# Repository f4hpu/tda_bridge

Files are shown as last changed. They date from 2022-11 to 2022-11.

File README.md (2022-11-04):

<h1 align="center">The tda_bridge Project</h1>




[FR en Français](./documentation/README_fr.md)

This repository contains a [KiCAD 6.0.9](https://www.kicad.org/) project for an electronics board (hardware).

This electronics board is a bridgeable audio stereo amplifier, based on a pair of TDA7293 chips.

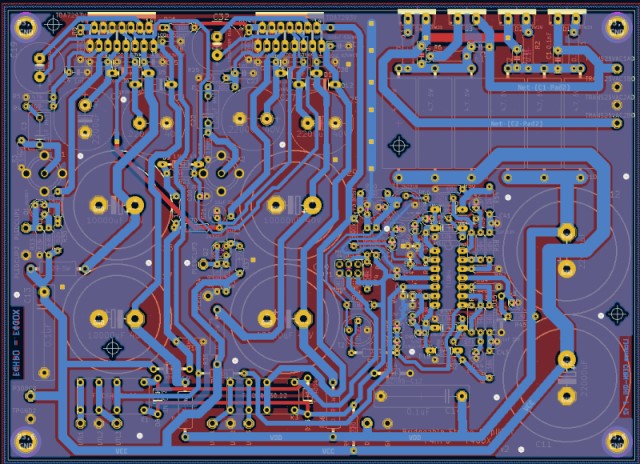
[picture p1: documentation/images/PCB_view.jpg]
PCB image


## Concept

The schematics around the TDA7293 was inspired by ST [datasheet](http://www.st.com/web/en/resource/technical/document/datasheet/CD00001887.pdf) and improved by [Francis Ibre for better sound.](http://www.cinetson.org/phpBB3/electronique-f13/1er-ampli-diy-question-diverse-t17238-30.html)

It includes onboard the same card both a power Supply and a watchdog to protect the loudspeakers against continuous voltage.

In addition, this stereo amplifier could easily be converted into a high power mono amplifier (bridge mode) by soldering R26, removing R28 and shunting R25.

## Historical background

A first implementation was made by authors (F4HPU and F4GUX) as reported in [Fangorn's blog](http://fangorn.over-blog.org/article-23233481.html).

Then, a first design was started using [Eagle (free version)](https://www.autodesk.fr/products/eagle/free-download) in 2014. The design then stoped as the size of the board was beyond the limitation of the free version of the CAD software.

Fortunately, in the mean time KiCAD team upgraded highly this wonderful tool and the project could be switched seamlessly to KiCAD 6.0.9.

For this historical reason, the 3D view of the card is not working well as there was no 3D view for the libraries converted from Eagle.

## Technical information

| Characteristics | Value |
| --- | --- |
| Output Power in 8 ohm | 2x70W (stereo) or 1x280W (bridged) |
| Circuit Dimensions | 176.5mm x 128.5 mm |

## Building a tda_bridge card

You have two options wether you wish to build the project as is (i.e. without using KiCAD), or tweak it to fit to your needs:

1. Download the [latest release](https://github.com/f4hpu/tda_bridge/releases/download/v0.0.0-alpha/fabrication.tar.gz) of this project "as is". This archive encloses a BOM (list of components), a directory with the gerber files, and useful pdf files.
2. or git clone this repo (or even download a zip of the directory) and install [KiCAD 6.0.9](https://www.kicad.org/) to open the project. From here, you can tweak the schematics, the routing and generate your Gerber files.

Once you have the gerber files, you can build the 2-sided PCB.

In case you wish to use a single sided PCB, authors guess that's possible if you put straps for the few missing connections. The ground plane effect may be less effective and the noise floor may rise up a little.

KiCAD offers the possibility to print a BOM to buy everything you need for the card by itself. But of course you may want to add some other stuffs, like the power supply transformer, a power switch, a potentiometer to control the output level, a box, a big heatsink (around ~0.4deg/W) for both the TDA7293's and the Diode's. You may find some inspiration in 
[Fangorn's blog - article 1](http://fangorn.over-blog.org/article-22214740.html)/[article 2](http://fangorn.over-blog.org/article-23233481.html), or [Erriez Guitar Amplifier](https://github.com/Erriez/DualTDA7293PowerAmplifier)

### Continuous voltage protection

A continuous voltage may arm the speaker. For this reason, authors included a circuit continuously watching both left and right outputs. In case of any failure both left and right speakers are disconnected.

The system is a custom design by F4HPU and F4GUX, which behavior was simulated using [LTSpice](https://www.analog.com/en/design-center/design-tools-and-calculators/ltspice-simulator.html).

A Jumper was included to select between using this watchdog, or bypassing it.

### Bridge mode

The Bridge mode is a special mode where the two lines of the stereo amplifier are used simultaneously to drive a single loudspeaker. Simply speaking, for an input signal V_in, left output is (A.V_in), while right output is (-A.V_in), therefore output between left and right is four times higher (as voltage is twice higher).

If you foresee to use this amplifier as a _stereo amplifier_ you need to: remove R26, solder R28, solder R25. In this case, the speakers shall be connected between ground and output_left for left speaker, and ground and output_right for right speaker.

But if you foresee to use this amplifier as a _high power mono amplifier_ you need to: solder R26, remove R28, replace R25 by a shunt. In this case, the speaker shall be connected between output_left and output_right.

## Licencing and Property

The design was made by F4HPU and F4GUX, who are [French Amateur Radio Operators.](https://www.r-e-f.org/)

Both Schematics and PCB are licensed under [CERN-OHL-P version 2](https://cern-ohl.web.cern.ch/home). 

IMPORTANT NOTE: CURRENT DESIGN HAS NEVER BEEN TESTED FOR REAL YET, SO BE CAREFULL, USE AT YOUR OWN RISKS.

For this reason, you are highly encouraged to check each functionnality step by step.

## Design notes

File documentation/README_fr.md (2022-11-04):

<h1 align="center">Projet tda_bridge</h1>




[ENUS in English](../README.md)

Ce dépôt contient un projet [KiCAD 6.0.9](https://www.kicad.org/) pour une carte électronique (hardware).

Cette carte électronique est un amplificateur stéréo audio avec option mode ponté (bridged), basé sur une paire de circuits TDA7293.

PCB image

## Concept

Le schéma autour du TDA7293 s'inspire de la [documentation ST](http://www.st.com/web/en/resource/technical/document/datasheet/CD00001887.pdf) et amélioré par [Francis Ibre pour un meilleur son.](http://www.cinetson.org/phpBB3/electronique-f13/1er-ampli-diy-question-diverse-t17238-30.html)

Il inclut sur la même carte à la fois une alimentation et un chien de garde pour protéger les haut-parleurs contre les tensions continues.

En outre, cet amplificateur stéréo pourrait facilement être converti en un amplificateur mono de haute puissance (mode pont) en soudant R26, en enlevant R28 et en shuntant R25.

## Bref historique

Une première implémentation a été réalisée par les auteurs (F4HPU et F4GUX) comme indiqué dans [le blog de Fangorn](http://fangorn.over-blog.org/article-23233481.html).

Ensuite, un premier design a été commencé en utilisant [Eagle (version libre)](https://www.autodesk.fr/products/eagle/free-download) en 2014. Le design s'est ensuite arrêté car la taille de la carte dépassait les limitations de la version gratuite du logiciel de CAO.

Heureusement, entre-temps, l'équipe de KiCAD a mis à niveau ce merveilleux outil et le projet a pu passer sans problème à KiCAD 6.0.9.

Pour cette raison historique, la vue 3D de la carte ne fonctionne pas bien car il n'y avait pas de vue 3D pour les bibliothèques converties depuis Eagle.

## Données Techniques

| Characteristiques | Valeurs |
| --- | --- |
| Puissance de Sortie dans 8 ohms | 2x70W (stereo) or 1x280W (ponté) |
| Dimensions du Circuit | 176.5mm x 128.5 mm |

## Construction d'une carte tda_bridge

Vous avez deux options : soit vous souhaitez construire le projet tel quel (c'est-à-dire sans utiliser KiCAD), soit vous souhaitez le modifier pour l'adapter à vos besoins :

1. Téléchargez la [dernière release] (https://github.com/f4hpu/tda_bridge/releases/download/v0.0.0-alpha/fabrication.tar.gz) de ce projet "tel quel". L'archive contient la BOM (liste de composants), un répertoire avec les fichiers gerber, et des fichiers pdf utiles.
2. ou clonez ce dépôt git (ou même téléchargez un zip du répertoire) et installez [KiCAD 6.0.9](https://www.kicad.org/) pour ouvrir le projet. A partir de là, vous pouvez modifier les schémas, le routage et générer vos fichiers Gerber.

Une fois que vous avez des fichiers gerber, vous pouvez construire le PCB double-face.

Si vous souhaitez utiliser un PCB simple face, les auteurs pensent que c'est possible si vous mettez des straps pour les quelques connexions manquantes. L'effet du plan de masse peut être moins efficace et le bruit de fond peut augmenter un peu.

KiCAD offre la possibilité d'imprimer une nomenclature pour acheter tout ce dont vous avez besoin pour la carte en elle-même. Mais bien sûr, vous pouvez vouloir ajouter d'autres choses, comme le transformateur d'alimentation, un interrupteur, un potentiomètre pour contrôler le niveau de sortie, un boîtier, un grand dissipateur thermique (environ ~0.4deg/W) à la fois pour les TDA7293 et les diodes. Vous pouvez trouver de l'inspiration dans
[blog de Fangorn - article 1](http://fangorn.over-blog.org/article-22214740.html)/[article 2](http://fangorn.over-blog.org/article-23233481.html), ou [l'ampli de guitare de Erriez](https://github.com/Erriez/DualTDA7293PowerAmplifier)

### Protection contre les tensions continues

Une tension continue peut abîmer un haut-parleur. Pour cette raison, les auteurs ont inclus un circuit qui surveille en permanence les deux sorties gauche et droite. En cas de défaillance, les haut-parleurs gauche et droit sont déconnectés.

Le système est une conception personnalisée par F4HPU et F4GUX, dont le comportement a été simulé en utilisant [LTSpice](https://www.analog.com/en/design-center/design-tools-and-calculators/ltspice-simulator.html).

Un cavalier a été inclus pour choisir d'utiliser ce chien de garde ou de le contourner.

### Mode ponté (Bridged)

Le mode ponté (bridged) est un mode spécial où les deux lignes de l'amplificateur stéréo sont utilisées simultanément pour piloter un seul haut-parleur. En clair, pour un signal d'entrée V_in, la sortie gauche est (A.V_in), tandis que la sortie droite est (-A.V_in). Ce faisant, la puissance de sortie se trouve quatre fois plus élevée (car la tension est deux fois plus élevée).

Si vous prévoyez d'utiliser cet amplificateur comme un _amplificateur stéréo_, vous devez : enlever R26, souder R28, souder R25. Dans ce cas, les enceintes doivent être connectées entre la masse et la sortie_gauche pour l'enceinte gauche, et la masse et la sortie_droite pour l'enceinte droite.

Mais si vous prévoyez d'utiliser cet amplificateur comme un _amplificateur mono de forte puissance_ vous devez : souder R26, enlever R28, remplacer R25 par un shunt (court-circuit). Dans ce cas, le haut-parleur doit être connecté entre output_left et output_right.

## Licences et propriété

La conception a été réalisée par F4HPU et F4GUX, qui sont [des radioamateurs français] (https://www.r-e-f.org/).

Les schémas et le PCB sont sous licence "Open Hardware" [CERN-OHL-P version 2](https://cern-ohl.web.cern.ch/home).

NOTE IMPORTANTE : LA CONCEPTION ACTUELLE N'A ENCORE JAMAIS ÉTÉ VRAIMENT TESTÉE, DONC SOYEZ PRUDENT, UTILISEZ À VOS PROPRES RISQUES.

Pour cette raison, vous êtes fortement encouragés à vérifier chaque fonctionnalité étape par étape.

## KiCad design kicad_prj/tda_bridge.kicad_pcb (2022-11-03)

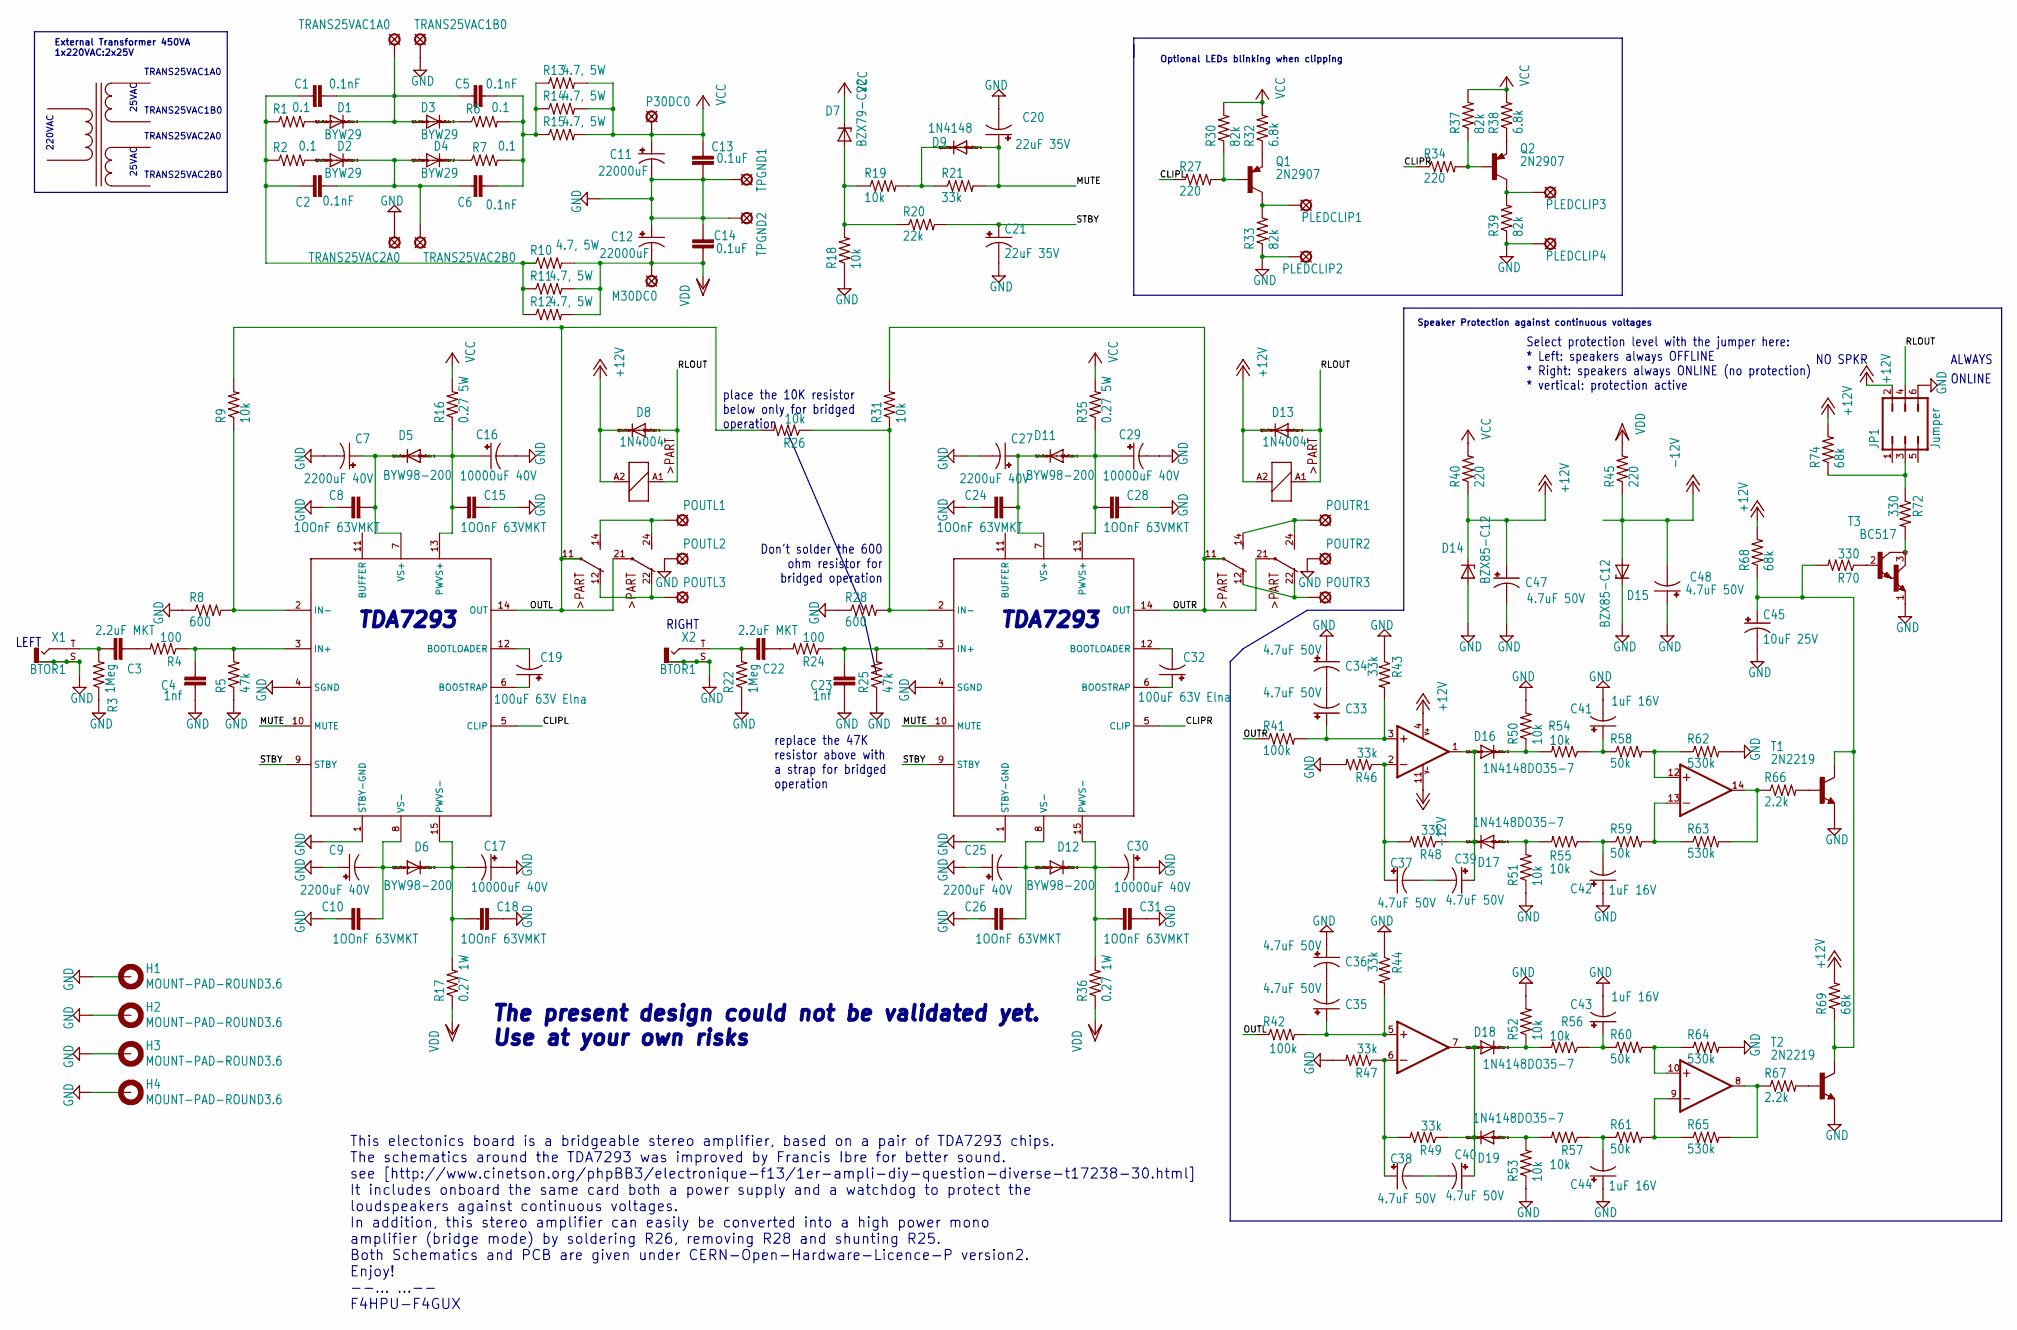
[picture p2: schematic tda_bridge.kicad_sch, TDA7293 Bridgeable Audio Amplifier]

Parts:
C1, C2, C5, C6: 0.1nF; C5B2.5
C3, C22: C075-063X106
C4, C23: C050-030X075
C7, C9, C25, C27: 2200uF 40V; E7,5-18
C8, C10, C15, C18, C24, C26, C28, C31: 1OOnF 63VMKT; C050-025X075
C11, C12: 22000uF; EB35D
C13, C14: 0.1uF; C22.5B6
C16, C17, C29, C30: 10000uF 40V; EB30D
C19, C32: 100uF 63V Elna; E5-13
C20, C21: 22uF 35V; E2-5
C33, C34, C35, C36, C37, C38, C39, C40, C47, C48: 4.7uF 50V; E1,8-4
C41, C42, C43, C44: 1uF 16V; E1,8-4
C45: 10uF 25V; E1,8-4
D1, D2, D3, D4: BYW29; DO220S
D5, D6, D11, D12: BYW98-200; F126-10
D7, D14, D15: DO41Z10
D8, D13: 1N4004; DO41-10
D9: 1N4148; DO35-10
D16, D17, D18, D19: 1N4148DO35-7; DO35-7
H1, H2, H3, H4: MOUNT-PAD-ROUND3.6; 3,6-PAD
IC1, IC2: TDA7293V; MULTIWATT15V
IC3: TL084; DIL14
JP1: Jumper; JP3Q
K1, K3: FINDER-30.22
M30DC0: SE13
P30DC0: SE13
PLEDCLIP1, PLEDCLIP2, PLEDCLIP3, PLEDCLIP4: SE13
POUTL1, POUTL2, POUTL3: SE13
POUTR1, POUTR2, POUTR3: SE13
Q1, Q2: 2N2907; TO18
R1, R2, R6, R7: 0.1; 0309_10
R3, R22: 1Meg; 0207_7
R4, R24: 100; 0207_7
R5, R25: 47k; 0207_7
R8, R28: 600; 0207_7
R9, R31: 10k; 0617_22
R10, R11, R12, R13, R14, R15: 4.7, 5W; VTA52
R16, R35: 0.27 5W; 0411_15
R17, R36: 0.27 1W; 0411_15
R18, R19, R26, R50, R51, R52, R53, R54, R55, R56, R57: 10k; 0207_7
R20: 22k; 0207_12
R21, R48, R49: 33k; 0207_7
R27, R34, R45: 220; 0207_7
R30, R33, R37, R39: 82k; 0207_7
R32, R38: 6.8k; 0207_7
R40: 220; 0207_12
R41: 100k; 0207_7
R42: 100k; 0207_12
R43, R44, R46, R47: 33k; 0207_2V
R58, R59, R60, R61: 50k; 0207_7
R62, R63, R64, R65: 530k; 0207_7
R66: 2.2k; 0207_7
R67: 2.2k; 0207_12
R68, R69, R74: 68k; 0207_7
R70, R72: 330; 0207_7
T1, T2: 2N2219; TO5
T3: BC517; TO92
T4: Transformer_1P_2S
TPGND1, TPGND2: SE13
TRANS25VAC1A0, TRANS25VAC1B0, TRANS25VAC2A0, TRANS25VAC2B0: SE13
X1, X2: BTOR1

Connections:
+12V: C47.+, D8.C, D13.C, D14.C, IC3.4 (V+), JP1.2, K1.A2 (2), K3.A2 (2), R40.1, R68.2, R69.2, R74.2
-12V: C48.-, D15.A, IC3.11 (V-), R45.1
/CLIPL: IC1.5 (CLIP), R27.1
/CLIPR: IC2.5 (CLIP), R34.1
/MUTE: C20.+, D9.A, IC1.10 (MUTE), IC2.10 (MUTE), R21.2
/OUTL: IC1.14 (OUT), K1.11, K1.21, R9.2, R26.2, R42.1
/OUTR: IC2.14 (OUT), K3.11, K3.21, R31.2, R41.1
/RLOUT: D8.A, D13.A, JP1.4, K1.A1 (1), K3.A1 (1)
/STBY: C21.+, IC1.9 (STBY), IC2.9 (STBY), R20.2
GND: C4.2, C7.-, C8.1, C9.+, C10.1, C11.-, C12.+, C13.2, C14.2, C15.1, C16.-, C17.+, C18.1, C20.-, C21.-, C23.2, C24.1, C25.+, C26.1, C27.-, C28.1, C29.-, C30.+, C31.1, C34.+, C36.+, C41.-, C42.+, C43.-, C44.+, C45.-, C47.-, C48.+, D14.A, D15.C, H1.B3,6 (MOUNT), H2.B3,6 (MOUNT), H3.B3,6 (MOUNT), H4.B3,6 (MOUNT), IC1.1 (STBY-GND), IC1.4 (SGND), IC2.1 (STBY-GND), IC2.4 (SGND), JP1.6, PLEDCLIP2.MP, PLEDCLIP4.MP, POUTL2.MP, POUTR2.MP, R3.1, R5.1, R8.1, R18.1, R22.1, R25.1, R28.1, R33.1, R39.1, R43.1, R44.1, R46.2, R47.2, R50.2, R51.1, R52.2, R53.1, R62.2, R64.2, T1.1 (E), T2.1 (E), T3.1 (E), TPGND1.MP, TPGND2.MP, TRANS25VAC1B0.MP, TRANS25VAC2A0.MP, X1.S (2), X1.S@1 (2@1), X1.S@2 (2@2), X1.S@3 (2@3), X2.S (2), X2.S@1 (2@1), X2.S@2 (2@2), X2.S@3 (2@3)
unnamed: C1.1, C2.1, R1.1, R2.1, R10.1, R11.1, R12.1
unnamed: C1.2, C5.1, D1.C, D3.A, TRANS25VAC1A0.MP
unnamed: C2.2, C6.1, D2.C, D4.A, TRANS25VAC2B0.MP
unnamed: C3.1, R3.2, X1.T (1)
unnamed: C3.2, R4.2
unnamed: C4.1, IC1.3 (IN+), R4.1, R5.2
unnamed: C5.2, C6.2, R6.2, R7.2, R13.1, R14.1, R15.1
unnamed: C7.+, C8.2, D5.C, IC1.7 (VS+)
unnamed: C9.-, C10.2, D6.A, IC1.8 (VS-)
unnamed: C15.2, C16.+, D5.A, IC1.13 (PWVS+), R16.1
unnamed: C17.-, C18.2, D6.C, IC1.15 (PWVS-), R17.2
unnamed: C19.+, IC1.6 (BOOSTRAP)
unnamed: C19.-, IC1.12 (BOOTLOADER)
unnamed: C22.1, R22.2, X2.T (1)
unnamed: C22.2, R24.2
unnamed: C23.1, IC2.3 (IN+), R24.1, R25.2
unnamed: C24.2, C27.+, D11.C, IC2.7 (VS+)
unnamed: C25.-, C26.2, D12.A, IC2.8 (VS-)
unnamed: C28.2, C29.+, D11.A, IC2.13 (PWVS+), R35.1
unnamed: C30.-, C31.2, D12.C, IC2.15 (PWVS-), R36.2
unnamed: C32.+, IC2.6 (BOOSTRAP)
unnamed: C32.-, IC2.12 (BOOTLOADER)
unnamed: C33.+, IC3.3 (+IN), R41.2, R43.2
unnamed: C33.-, C34.-
unnamed: C35.+, IC3.5 (+IN), R42.2, R44.2
unnamed: C35.-, C36.-
unnamed: C37.+, IC3.2 (-IN), R46.1, R48.2
unnamed: C37.-, C39.-
unnamed: C38.+, IC3.6 (-IN), R47.1, R49.2
unnamed: C38.-, C40.-
unnamed: C39.+, D16.A, D17.C, IC3.1 (OUT), R48.1
unnamed: C40.+, D18.A, D19.C, IC3.7 (OUT), R49.1
unnamed: C41.+, R54.1, R58.1
unnamed: C42.-, R55.1, R59.1
unnamed: C43.+, R56.1, R60.1
unnamed: C44.-, R57.1, R61.1
unnamed: D1.A, R1.2
unnamed: D2.A, R2.2
unnamed: D3.C, R6.1
unnamed: D4.C, R7.1
unnamed: D7.A, R18.2, R19.1, R20.1
unnamed: D9.C, R19.2, R21.1
unnamed: D16.C, R50.1, R54.2
unnamed: D17.A, R51.2, R55.2
unnamed: D18.C, R52.1, R56.2
unnamed: D19.A, R53.2, R57.2
unnamed: IC1.2 (IN-), R8.2, R9.1
unnamed: IC2.2 (IN-), R26.1, R28.2, R31.1
unnamed: IC3.8 (OUT), R65.2, R67.1
unnamed: IC3.9 (-IN), R61.2, R65.1
unnamed: IC3.10 (+IN), R60.2, R64.1
unnamed: IC3.12 (+IN), R58.2, R62.1
unnamed: IC3.13 (-IN), R59.2, R63.1
unnamed: IC3.14 (OUT), R63.2, R66.1
unnamed: JP1.3, R72.1, R74.1
unnamed: K1.12 (O), K1.22 (O), POUTL3.MP
unnamed: K1.14 (S), K1.24 (S), POUTL1.MP
unnamed: K3.12 (O), K3.22 (O), POUTR3.MP
unnamed: K3.14 (S), K3.24 (S), POUTR1.MP
unnamed: PLEDCLIP1.MP, Q1.3 (C), R33.2
unnamed: PLEDCLIP3.MP, Q2.3 (C), R39.2
unnamed: Q1.1 (E), R32.1
unnamed: Q1.2 (B), R27.2, R30.1
unnamed: Q2.1 (E), R38.1
unnamed: Q2.2 (B), R34.2, R37.1
unnamed: R66.2, T1.2 (B)
unnamed: R67.2, T2.2 (B)
unnamed: C45.+, R68.1, R69.1, R70.2, T1.3 (C), T2.3 (C)
unnamed: R70.1, T3.2 (B)
unnamed: R72.2, T3.3 (C)
VCC: C11.+, C13.1, D7.C, P30DC0.MP, R13.2, R14.2, R15.2, R16.2, R30.2, R32.2, R35.2, R37.2, R38.2, R40.2
VDD: C12.-, C14.1, M30DC0.MP, R10.2, R11.2, R12.2, R17.1, R36.1, R45.2

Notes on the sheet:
25VAC
TRANS25VAC1A0
ALWAYS
Optional LEDs blinking when clipping
TDA7293
ONLINE
NO SPKR
This electonics board is a bridgeable stereo amplifier, based on a pair of TDA7293 chips. The schematics around the TDA7293 was improved by Francis Ibre for better sound. see [http://www.cinetson.org/phpBB3/electronique-f13/1er-ampli-diy-question-diverse-t17238-30.html] It includes onboard the same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
TRANS25VAC1B0
LEFT
Don't solder the 600 ohm resistor for bridged operation
220VAC
The present design could not be validated yet. Use at your own risks
TRANS25VAC2B0
place the 10K resistor below only for bridged operation
RIGHT
Select protection level with the jumper here: * Left: speakers always OFFLINE * Right: speakers always ONLINE (no protection) * vertical: protection active
Speaker Protection against continuous voltages
TRANS25VAC2A0
replace the 47K resistor above with a strap for bridged operation
External Transformer 450VA 1x220VAC:2x25V

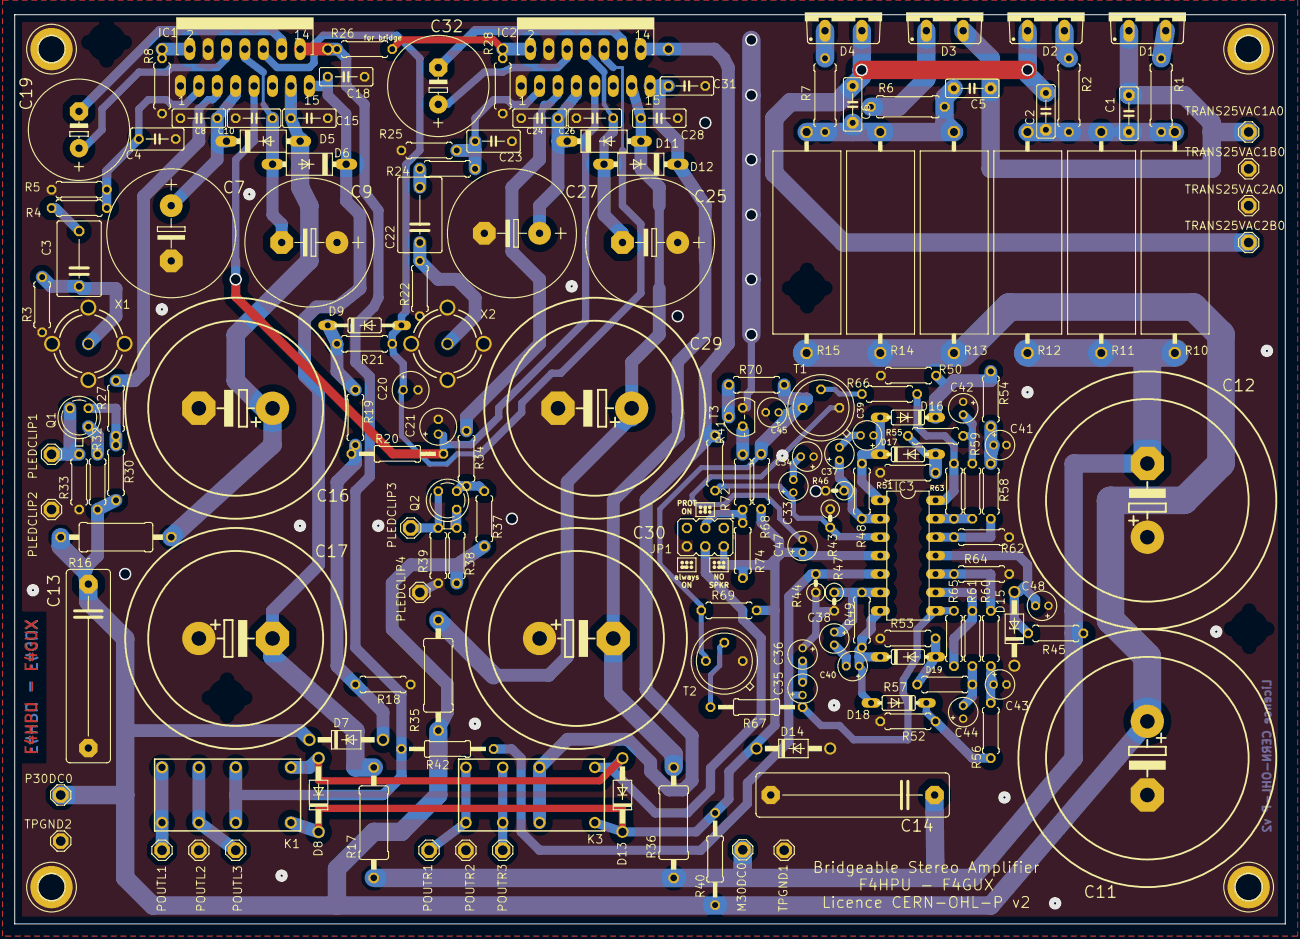
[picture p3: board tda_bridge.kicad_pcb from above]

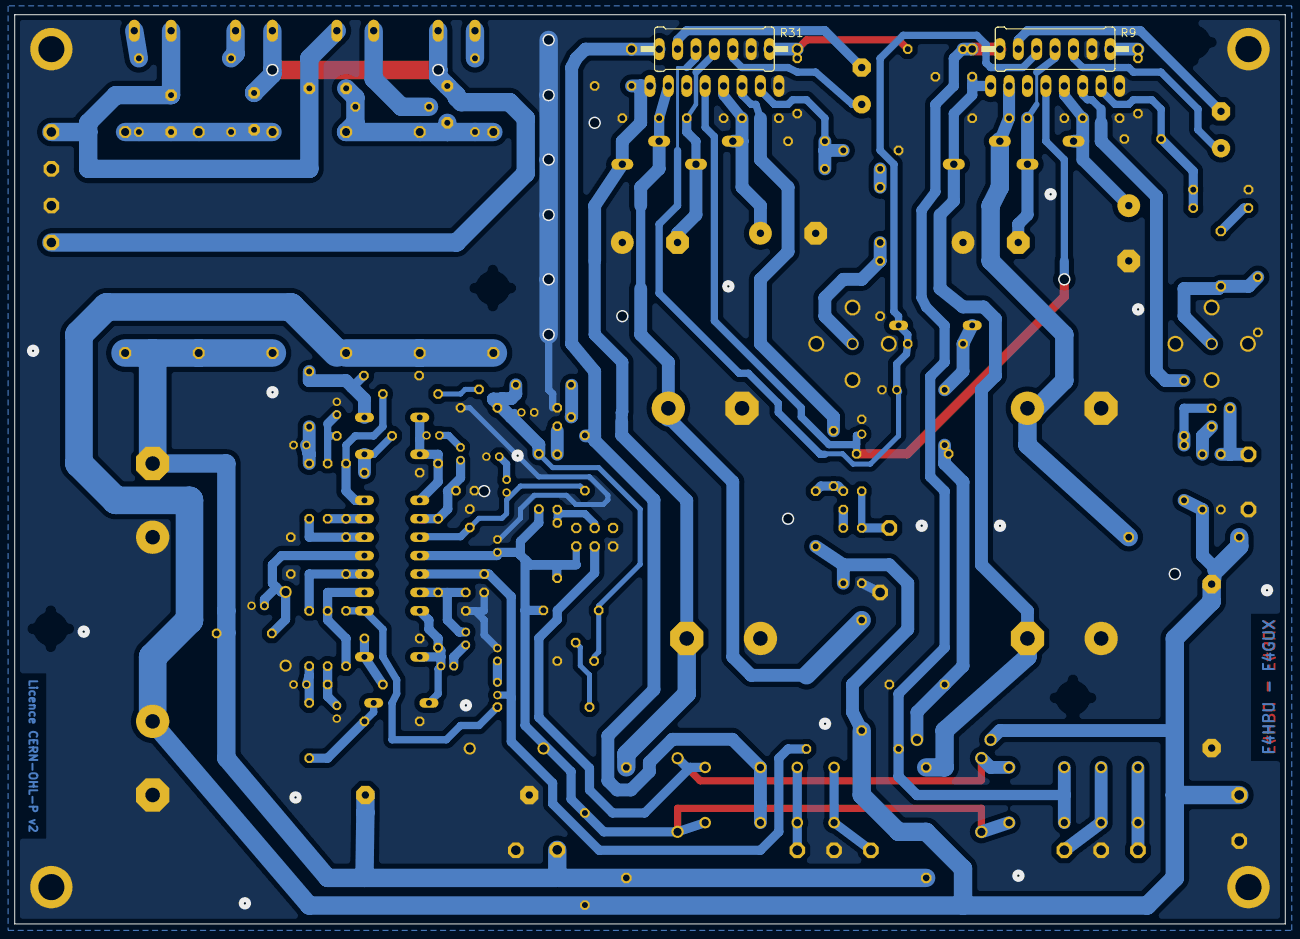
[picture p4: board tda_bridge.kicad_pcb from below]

Board: 2 copper layers, 175.2 x 125.4 mm, 170 parts (2 on the bottom side), 82 nets.

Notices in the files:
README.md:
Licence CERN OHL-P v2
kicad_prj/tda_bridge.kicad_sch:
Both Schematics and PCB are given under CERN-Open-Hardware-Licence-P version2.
